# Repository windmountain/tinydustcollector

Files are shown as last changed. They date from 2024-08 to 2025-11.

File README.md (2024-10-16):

# Tiny Dust Collector

Using a shop vac for sawdust and woodchips makes a mess when you go to empty it or (God forbid) unclog the filter.

Big wood shops can use a proper dust collector even if it takes up a lot of space.

But what if you don't have a lot of space?

Oneida Air Systems makes a product called the [Dust Deputy](https://www.oneida-air.com/dust-deputy) that you can bolt onto a five-gallon bucket and a shop vac. It will slow down the bigger dust particles by spinning them around in a funnel, like would happen inside a normal dust collector, and keep most of the dust out of the shop vac.

But what if you don't have a lot of space for a five gallon bucket and a big round shop vac?

Smaller shop vacs like the [RIDGID 3 Gallon 5.0 Peak HP NXT](https://www.homedepot.com/p/RIDGID-3-Gallon-5-0-Peak-HP-NXT-Shop-Vac-Wet-Dry-Vacuum-with-Fine-Dust-Filter-Expandable-Hose-and-Accessory-Attachments-HD0300/320181466) are about the size of a toolbox. They'll work in an upright position if you find the valve that closes when they're picking up liquid and hold it open with a rubber band.

Instead of the 5-gallon bucket, you can bolt the Oneida Air Systems Dust Deputy onto a firmly sealing plastic box.

## An Enclosure

Here's my design for a plywood enclosure that holds these three things together so that they don't pull apart and tip over during use. It also helps a bit keeping the noise of the shop vac down.

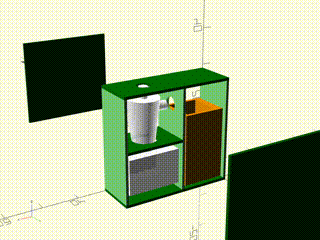
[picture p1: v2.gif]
3D computer model of enclosure with Oneida Air Systems Dust Deputy, plastic box, and shop vac installed


The .scad file can be opened with [OpenSCAD](https://openscad.org). Units are in inches.

It's 29 inches tall, 32 inches wide, and 13-1/2 inches deep. Joinery is left as an exercise for the reader (I went with dowels).

I also wound up installing the front panel on [frameless, full overlap](https://www.rockler.com/blumreg-110deg-soft-close-blumotion-clip-top-overlay-hinges-for-frameless-cabinets-hinges) hinges and drilling a bunch of holes in the back for shop vac exhaust.

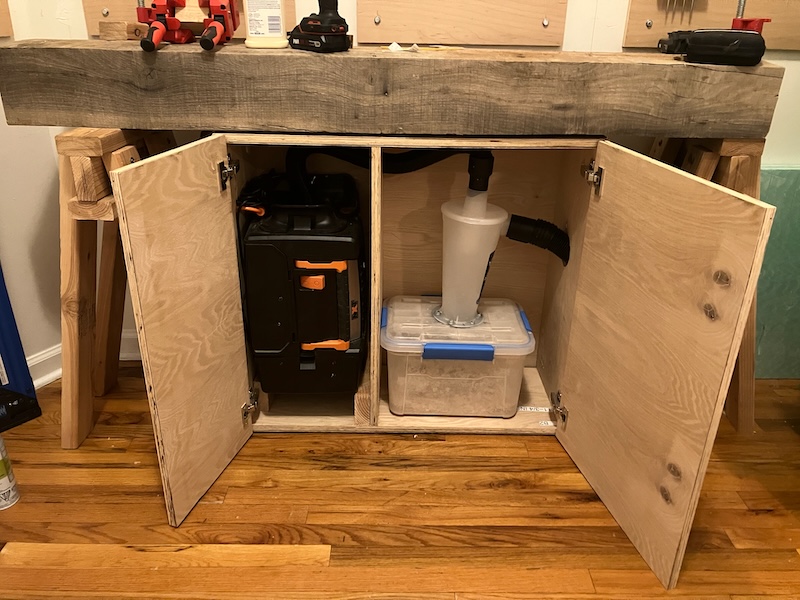
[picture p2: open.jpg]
Dust collector with cabinet doors open

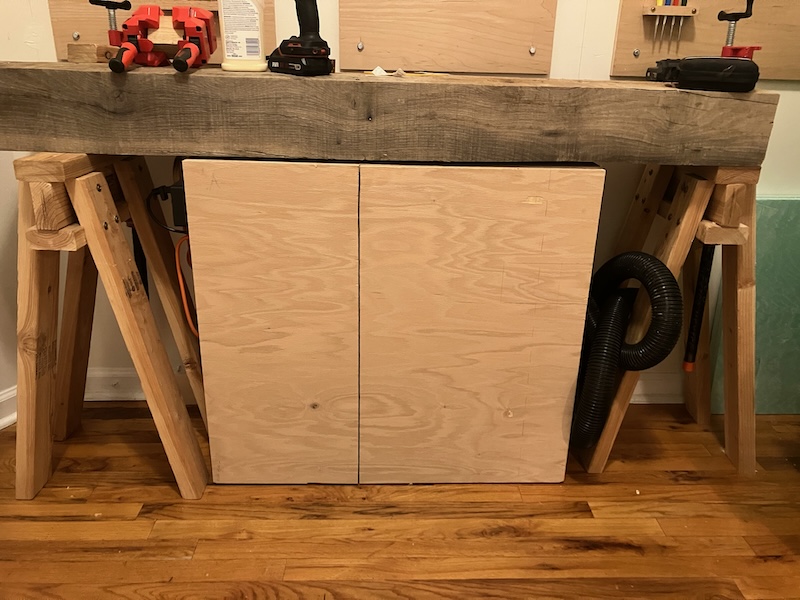
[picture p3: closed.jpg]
Dust collector with cabinet doors closed


## Does it work?

Amazingly, it does!

Given the tight angles of everything, I was expecting about half of the dust to make it to through the funnel and the other half to wind up in the shop vac. Imagine my surprise when emptying out the chips and seeing this inside the shop vac:

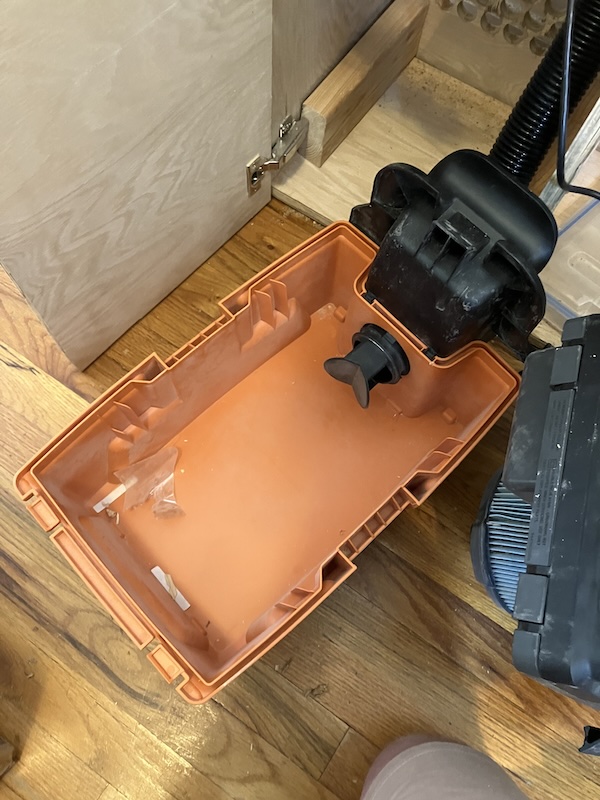
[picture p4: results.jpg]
Shop vac open with no sawdust or woodchips inside


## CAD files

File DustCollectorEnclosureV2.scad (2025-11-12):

/*
  RIDGID 3 Gallon 5.0 Peak HP NXT shop vac
*/
module shopVac() {
    vacWidth = 19.5;
    vacDepth = 11;
    vacHeight = 12;

    inflowHeight = 4;
    inflowInset = 3.5;

    switchWidth = 1.5;
    switchDepth = 2.5;
    switchHeight = 1; // doesn't really matter, just needs to be consistent
    switchDepthOffset = 3.5;
    switchWidthOffset = 6.5;

    color("orange", 1) {
        difference() {
            cube([vacWidth, vacDepth, vacHeight]);
            translate([vacWidth - inflowInset - 1, 1, 1]) {
                cube([inflowInset + 2, vacDepth - 2, inflowHeight + 5]);
            }
        }
    }
    color("black", 1.0) {
        translate([vacWidth - inflowInset - 1, vacDepth / 2, inflowHeight]) {
            rotate([0, 90, 0]) {
                cylinder(h = 1, r = 1.25, $fn = 20);
            }
        }
    }
    color("grey", 1.0) {
        translate([vacWidth - switchWidthOffset, switchDepthOffset, vacHeight - switchHeight + 0.1]) {
            cube([switchWidth, switchDepth, switchHeight]);
        }
    }
}


/*
  Tupperware (airtight) chip collector
*/
module tupperware() {
    chipWidth = 15;
    chipHeight = 9.5;
    chipDepth = 11.25;

    color("white", 0.85) 
        cube([chipWidth, chipDepth, chipHeight]);
}

/*
  Cyclonic "dust deputy" from Oenida Air Systems
*/
module dustDeputy() {
    deputyConeHeight = 13.5;
    deputyBottomRadius = 3;
    deputyTopRadius = 4.5;

    color("white", 0.85) {
        cylinder(
            h = deputyConeHeight,
            r1 = deputyBottomRadius,
            r2 = deputyTopRadius,
            $fn = 90
        );
        translate([deputyTopRadius * 0.3, 0, deputyConeHeight - 3]) {
            rotate([0, 90, 0]) {
                cylinder(h = 5, r = 1.25, $fn = 20);
            }
        }
        translate([0, 0, deputyConeHeight]) {
            rotate([0, 0, 0]) {
                cylinder(h = 3, r = 1.25, $fn = 20);
            }
        }
    }
}

/*
  Build from 3/4 inch plywood with dowel or biscuit joinery.
*/
module cabinet() {
    overallDepth = 12;
    overallWidth = 32;
    overallHeight = 29;

    // bottom
    color("green", 1.0) {
        cube([overallWidth, overallDepth, 0.75]);
    }

    // top
    color("green", 1.0) {
        translate([0, 0, overallHeight - 0.75]) {
            cube([overallWidth, overallDepth, 0.75]);
        }
    }

    // side 1
    color("lightgreen") {
        translate([0, 0, 0.75]) {
            cube([0.75, overallDepth, overallHeight - (0.75 * 2)]);
        }
    }

    // side 2
    color("lightgreen") {
        translate([overallWidth - 0.75, 0, 0.75]) {
            difference() {
                cube([0.75, overallDepth, overallHeight - (0.75 * 2)]);
                translate([-0.25, 5.75, 19.25]) {
                    rotate([0, 90, 0]) {
                        cylinder(h = 1.25, r = 2, $fn = 20);
                    }
                }
            }
        }
    }

    // center divider
    color("lightgreen") {
        translate([14, 0, 0.75]) {
            difference() {
                cube([0.75, overallDepth, overallHeight - (0.75 * 2)]);
                translate([-0.25, 5.75, 19.25 + 5]) {
                    rotate([0, 90, 0]) {
                        cylinder(h = 1.25, r = 2, $fn = 20);
                    }
                }
            }
        }
    }
    // front
    color("darkgreen") {
        translate([0, -0.75 - 027, 0]) {
            cube([overallWidth, 0.75, overallHeight]);
        }
    }
    // back
    color("darkgreen") {
        translate([0, 12, 0]) {
            cube([overallWidth, 0.75, overallHeight]);
        }
    }
}

// Assembly:

cabinet();

translate([13, 0, 1]) {
    rotate([0, -90, 0]) {
        shopVac();
    }
}

translate([15.5, 0, 0.75]) {
    tupperware();
}

translate([23, 5.5, 9.5]) {
    dustDeputy();
}

/*

NOT SHOWN:

1. Hose from shop vac through the hole in the center divider and to the top of the Dust Deputy.
2. Anti-implosion baffle inside tupperware. (Two pieces of plywood hot glued together to keep the box from imploding at max suction.)

*/

echo(version=version());

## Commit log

2024-08-07 Add SCAD model of tiny dust collector enclosure
    [DustCollectorEnclosureV2.scad]
2025-11-07 Move some pieces out to their own modules
    [DustCollectorEnclosureV2.scad]
2025-11-12 Correct cabinet holes
    [DustCollectorEnclosureV2.scad]
